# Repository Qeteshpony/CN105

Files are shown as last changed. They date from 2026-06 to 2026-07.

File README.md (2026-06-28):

# Mitsubishi CN105 compatible heatpump controller for ESPHome and Home Assistant



3D Render

[Hardware Documentation](https://qeteshpony.github.io/CN105)

## Hardware fabrication

I ordered these boards from JLCPCB (Not a sponsor) and had only the smd components on the top side assembled. You then still need an ESP32-C6-WROOM-1 module (gets soldered on the bottom) and a Gaptec LME78_03-1.0 DC/DC Regulator. Also some header pins and a cable with a JST PAP-V-S PA 2.0 5 pin connector which goes into the CN105 port on the heatpumps main board. 

### Some details about the hardware

I decided to use the DC/DC regulator and pull power from the 12V pin of the heatpump since the 5V pin can't handle much current and I didn't want to risk damaging the heatpump. The 5V pin is just used for the pullups on the logic level converter since the heatpumps CN105 connector uses 5V logic which the ESP can't handle properly. 

LEDs 1 and 2 are connected to GPIO 23 and 22 and can be used freely by your software. 

LEDs 3 and 4 show activity on TX and RX and can be left out if you don't want the module to blink all the time... 

## Software

Mine are running with ESPHome and the external component found at [github.com/echavet/MitsubishiCN105ESPHome](https://github.com/echavet/MitsubishiCN105ESPHome)

Since this board uses the ESP32-C6, it can use WiFi as well as Thread to communicate with Home Assistant. 

Keep in mind that cheap serial adapters might not deliver enough power to successfully flash the ESP. I had to feed external power while flashing it. In that case only connect GND, RX and TX of the UART0 header to your serial adapter and feed anything between 6 and 36 volts (That's what the LME78 can handle) into the 12V pin of the boards CN105 header. 
When using ESPHome this is also just needed once. Updates can then be installed OTA.

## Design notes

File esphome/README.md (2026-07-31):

# Example YAML

This is the yaml I use for my AC units. Make sure to go through all the options to see if it fits your device before installing it. 

Most of the configuration comes from examples at https://github.com/echavet/MitsubishiCN105ESPHome with some added bits and pieces...

### Dew Point Control

I added a simple dew point control that gets active the moment the AC is set to dry mode. It uses the dew point sensor and adds 10°C to move it into the valid area for the AC. So if you want to get to a dew point of 13°C set the AC to dry and 23°C

When switching modes it takes a few seconds for the temperature to update. No worries if it doesn't happen immediately.

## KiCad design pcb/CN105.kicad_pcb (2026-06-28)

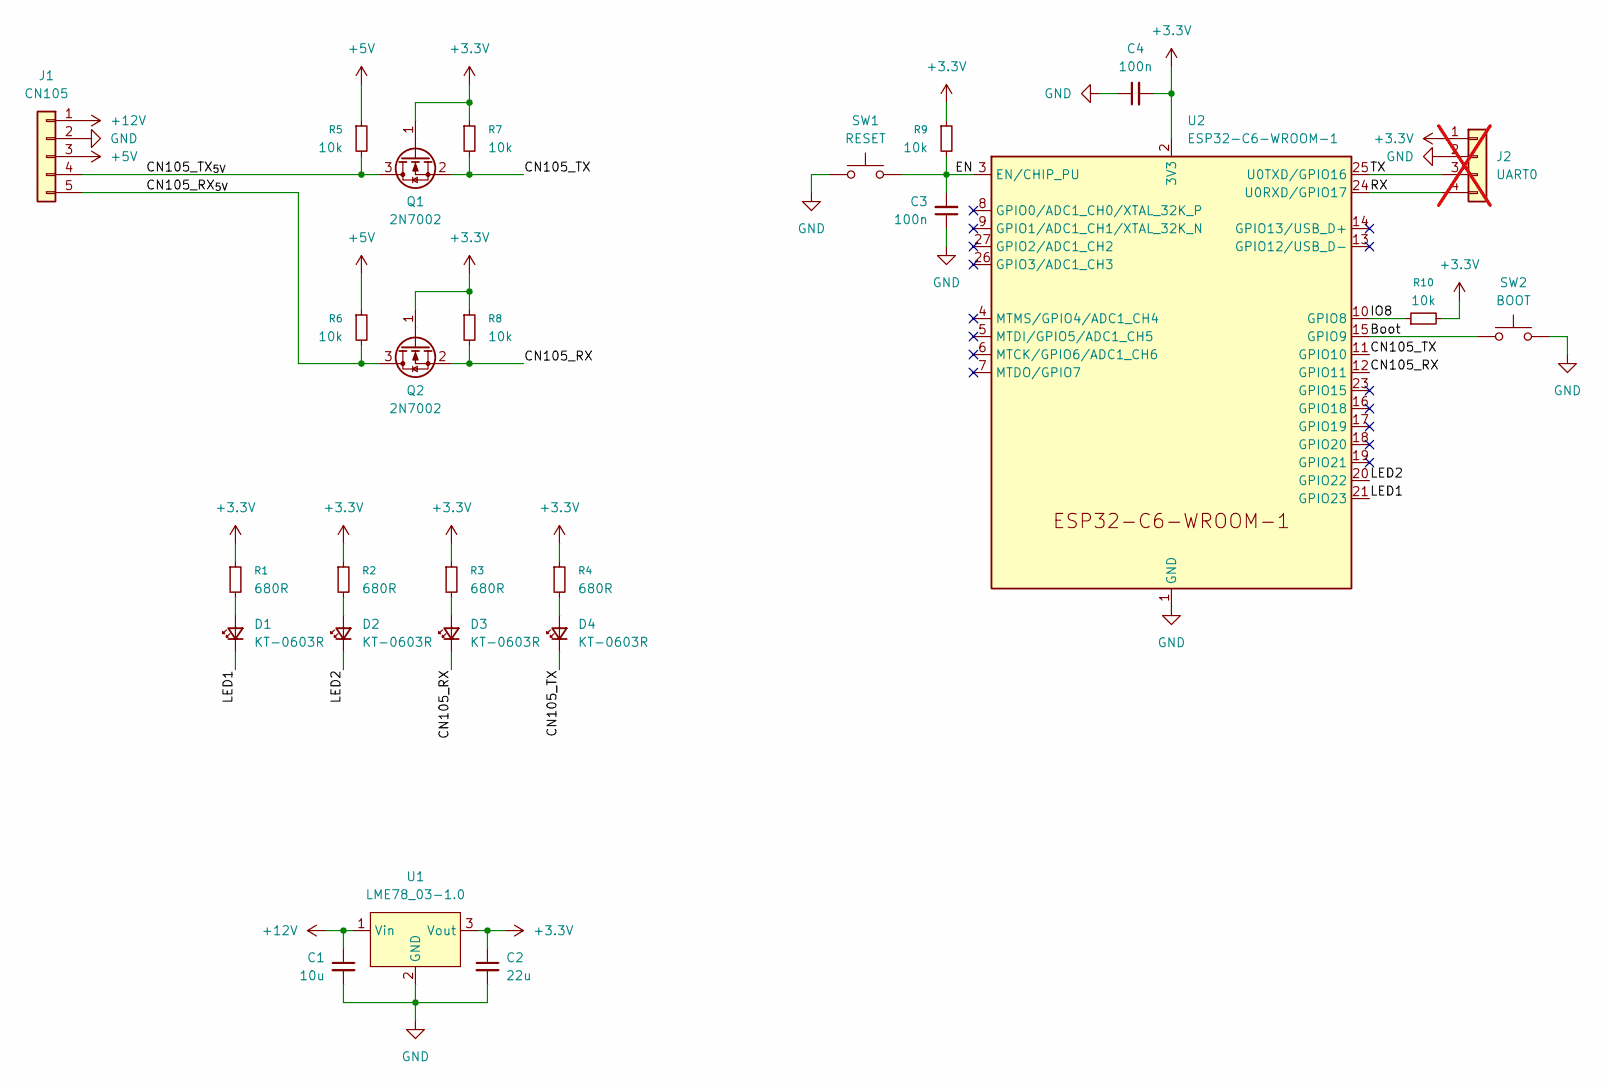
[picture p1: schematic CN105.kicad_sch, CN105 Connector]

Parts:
C1: 10u; C_0805_2012Metric; LCSC C440198
C2: 22u; C_0805_2012Metric; LCSC C45783
C3, C4: 100n; C_0402_1005Metric; LCSC C1525
D1, D2, D3, D4: KT-0603R; LED_0603_1608Metric; LCSC C2286
J1: CN105; PinHeader_1x05_P2.54mm_Horizontal
J2: UART0; PinHeader_2x02_P2.54mm_Vertical; not fitted
Q1, Q2: 2N7002; SOT-23; LCSC C8545
R1, R2, R3, R4: 680R; R_0402_1005Metric; LCSC C25130
R5, R6, R7, R8, R9, R10: 10k; R_0402_1005Metric; LCSC C25744
SW1: RESET; SW_Push_SPST_NO_Alps_SKRK; LCSC C720477
SW2: BOOT; SW_Push_SPST_NO_Alps_SKRK; LCSC C720477
U1: LME78_03-1.0; LME78_1.0-Series
U2: ESP32-C6-WROOM-1

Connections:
+3.3V: C2.1, C4.2, J2.1, Q1.1 (G), Q2.1 (G), R1.1, R2.1, R3.1, R4.1, R7.1, R8.1, R9.1, R10.2, U1.3 (Vout), U2.2 (3V3)
+5V: J1.3, R5.1, R6.1
+12V: C1.1, J1.1, U1.1 (Vin)
/Boot: SW2.1, U2.15 (GPIO9)
/CN105_RX: D3.1 (K), Q2.2 (S), R8.2, U2.12 (GPIO11)
/CN105_RX_{5V}: J1.5, Q2.3 (D), R6.2
/CN105_TX: D4.1 (K), Q1.2 (S), R7.2, U2.11 (GPIO10)
/CN105_TX_{5V}: J1.4, Q1.3 (D), R5.2
/EN: C3.2, R9.2, SW1.2, U2.3 (EN/CHIP_PU)
/IO8: R10.1, U2.10 (GPIO8)
/LED1: D1.1 (K), U2.21 (GPIO23)
/LED2: D2.1 (K), U2.20 (GPIO22)
/RX: J2.4, U2.24 (U0RXD/GPIO17)
/TX: J2.3, U2.25 (U0TXD/GPIO16)
GND: C1.2, C2.2, C3.1, C4.1, J1.2, J2.2, SW1.1, SW2.2, U1.2 (GND), U2.1 (GND), U2.28 (GND), U2.29 (GND)
unnamed: D1.2 (A), R1.2
unnamed: D2.2 (A), R2.2
unnamed: D3.2 (A), R3.2
unnamed: D4.2 (A), R4.2

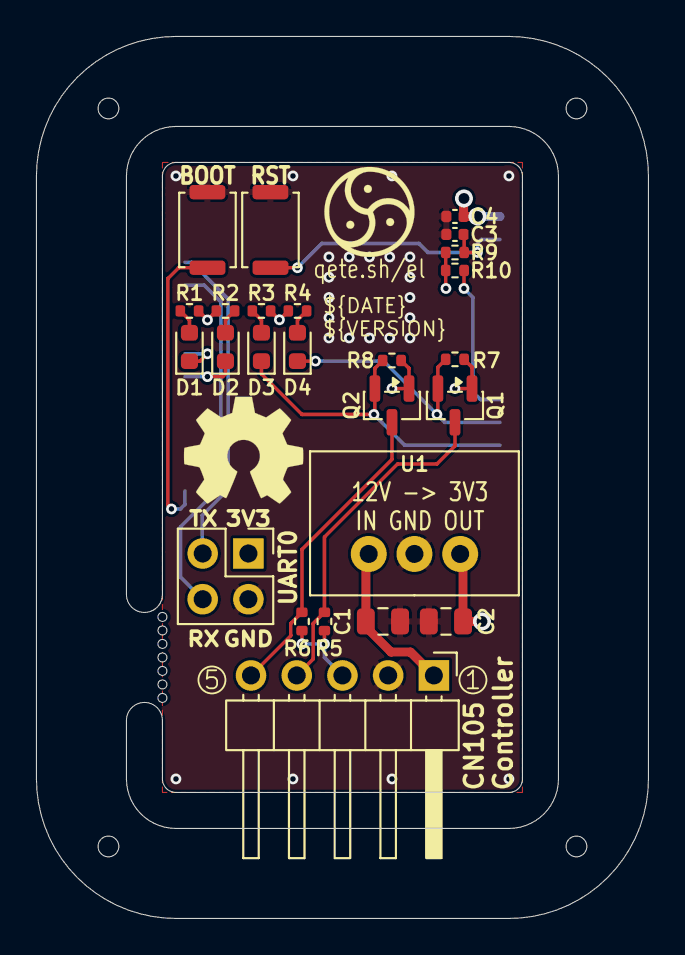
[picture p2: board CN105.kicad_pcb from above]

Board: 4 copper layers, 34.0 x 49.0 mm, 27 parts (1 on the bottom side), 19 nets.

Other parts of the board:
mouse-bite-2mm-slot: VAL**; mouse-bite-2x5mm-slot-onesided-v2

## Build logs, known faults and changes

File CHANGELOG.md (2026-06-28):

# Changelog

## 1.0.0 (2026-06-28)

### Features

* initial commit ([f1c66b6](https://github.com/Qeteshpony/CN105/commit/f1c66b6623ab938a73027c36b96301bc91ebb241))

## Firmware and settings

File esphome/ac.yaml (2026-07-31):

substitutions:
  name: ac  # device name
  friendly_name: AC  
  remote_temp_sensor: sensor.thermostat_actual_temperature  # external temperature sensor
  remote_dewpoint_sensor: sensor.thermostat_dew_point  # external dewpoint sensor (used for dry mode)
  temp_offset: 0.0  # temperature offset added to external sensor readings (My AC cools to 1°C below the set temperature so I set this to -0.5)
  api_key: "5NPD5ZrHBdZ8N1r60qwq8+gZfK6wUh1ccB4uV7eUhDU="  # randomly generated key. Make sure to use your own... or not... I'm not your mom... 

esphome:
  name: ${name}
  friendly_name: ${friendly_name}
  comment: Dummy device
  project:
    name: Qetesh.CN105-Controller
    version: 1.0.0

esp32:
  variant: esp32c6
  framework:
    type: esp-idf

# External component reference
external_components:
  - source: github://echavet/MitsubishiCN105ESPHome
    
logger:
  level: INFO
  logs:
    EVT_SETS: INFO
    WIFI: INFO
    MQTT: INFO
    WRITE_SETTINGS: INFO
    SETTINGS: INFO
    STATUS: INFO
    CN105Climate: WARN
    CN105: INFO
    climate: WARN
    sensor: WARN
    chkSum: INFO
    WRITE: WARN
    READ: WARN
    Header: INFO
    Decoder: INFO
    CONTROL_WANTED_SETTINGS: INFO

api:
  encryption:
    key: ${api_key}

ota:
  - platform: esphome

wifi:
  ssid: !secret wifi_ssid
  password: !secret wifi_password
  ap:
    ssid: ${friendly_name} ESP
    password: "WiFiPassword"

captive_portal:

sensor:
  # Uptime sensor.
  - platform: uptime
    name: Uptime

  # WiFi Signal sensor.
  - platform: wifi_signal
    name: WiFi Signal
    update_interval: 120s

  - platform: homeassistant
    name: "Remote Temperature Sensor"
    entity_id: ${remote_temp_sensor}
    id: ha_remote_temp
    internal: true
    force_update: true
    on_value:
      then:
        - lambda: id(ha_effective_temp).update();

  - platform: homeassistant
    name: "Remote Dewpoint Sensor"
    entity_id: ${remote_dewpoint_sensor}
    id: ha_remote_dewpoint
    internal: true
    force_update: true
    on_value:
      then:
        - lambda: id(ha_effective_temp).update();

  - platform: template
    name: "Effective Temperature Value"
    id: ha_effective_temp
    internal: false
    entity_category: diagnostic
    force_update: false
    unit_of_measurement: "°C"
    device_class: temperature
    lambda: |-
      if (id(hp).mode == climate::CLIMATE_MODE_DRY) {
        ESP_LOGI("virtualsensor", "ha_effective_temp update using dewpoint");
        return id(ha_remote_dewpoint).state + 10.0f;
      } else {
        ESP_LOGI("virtualsensor", "ha_effective_temp update using temperature");
        return id(ha_remote_temp).state;
      }
    filters:
      - offset:
          ${temp_offset}

# Enable Web server.
web_server:
  port: 80

# Sync time with Home Assistant.
time:
  - platform: homeassistant
    id: homeassistant_time

text_sensor:
  # Expose ESPHome version as sensor.
  - platform: version
    name: ESPHome Version
  # Expose WiFi information as sensors.
  - platform: wifi_info
    ip_address:
      name: IP
    ssid:
      name: SSID
    bssid:
      name: BSSID

# Create a button to restart the unit from HomeAssistant. Rarely needed, but can be handy.
button:
  - platform: restart
    name: "Restart ${friendly_name}"

# Do not change the uart settings!    
uart:
  id: HP_UART
  baud_rate: 2400
  tx_pin: GPIO11
  rx_pin: GPIO10
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

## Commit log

2026-06-28 feat: initial commit
    [CN105.kicad_pcb, CN105.kicad_sch]
2026-06-28 ci: switch to main branch of reusable workflows
